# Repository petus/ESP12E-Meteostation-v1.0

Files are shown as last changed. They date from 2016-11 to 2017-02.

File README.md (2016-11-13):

# ESP12E-Meteostation-v1.0<br>
Meteostation with ESP12E (NodeMCU) and Si7021 (temperature and humidity sensor)<br>
<br>
PCB is designed in eagle<br>
The platic box is KM-27<br>
<br>
FLASHING: <br>
 1.) Choose NodeMCU v1.0 (ESP12E Module) in Tools -> Board<br>
for NodeMCU board:<br>
 2.) Upload the code<br>
for PCB with ESP12E:<br>
 2.) Press the Reset button and Flash button together and hold it<br>
 3.) Click to Upload the code in Arduino IDE<br>
 4.) In the moment when the console shows <strong>Uploading</strong> leave the Reset button, then the code will be uploaded<br>
<br>
websites: <br>
CZ http://chiptron.petus.cz/articles.php?article_id=93 <br>
EN http://time4ee.com/articles.php?article_id=33 <br>

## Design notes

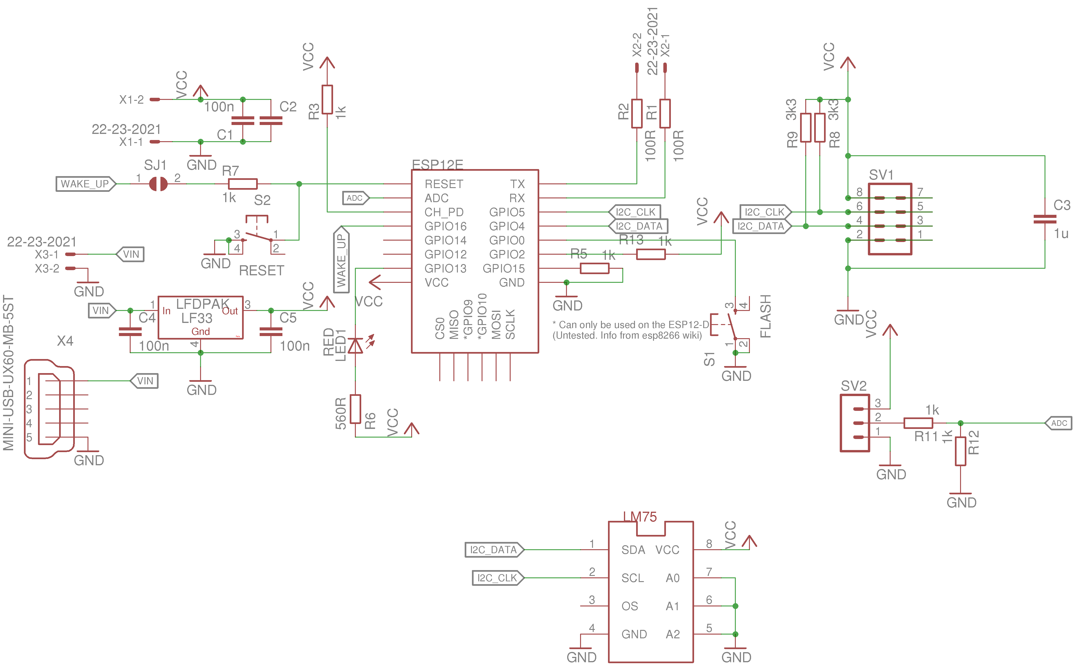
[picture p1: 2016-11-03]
ESP12E_ESP8266_Si7021_meteostation_SCH.png

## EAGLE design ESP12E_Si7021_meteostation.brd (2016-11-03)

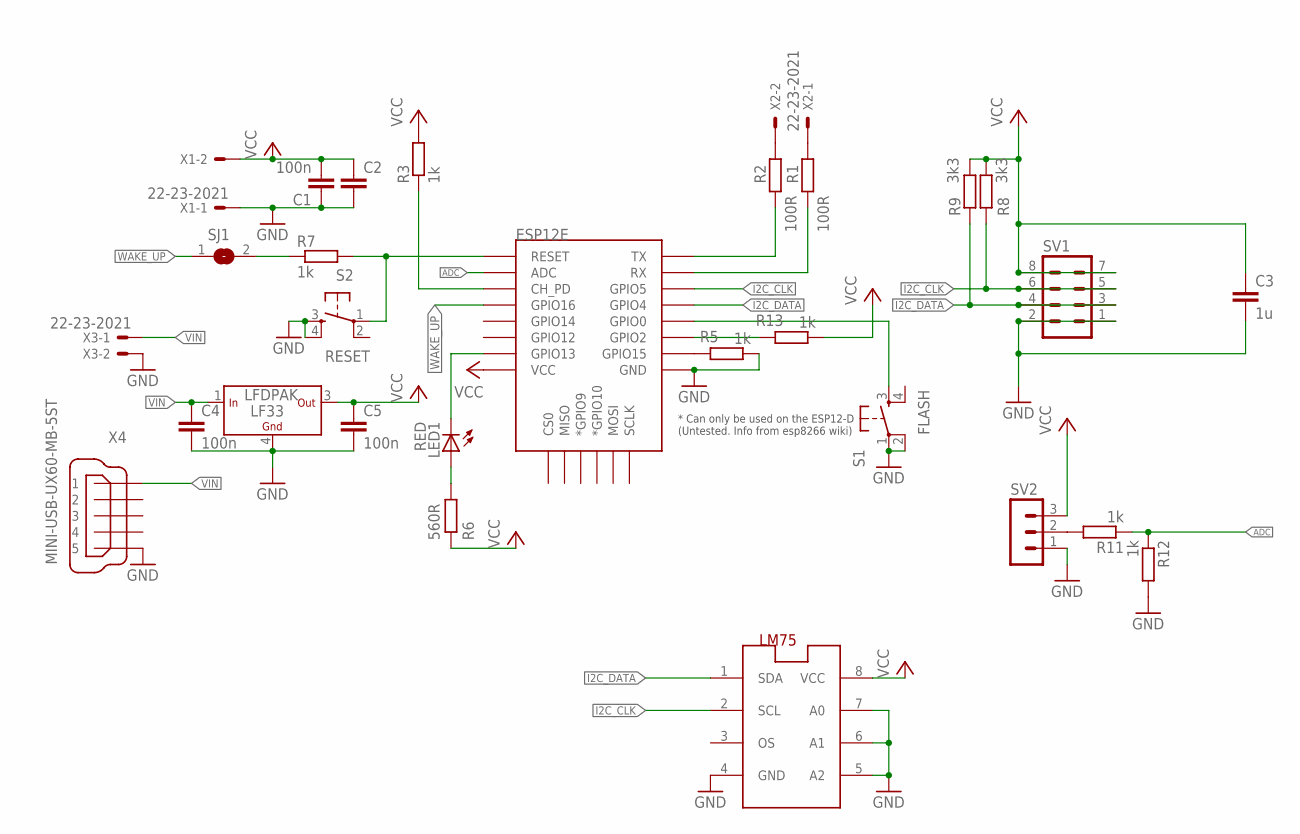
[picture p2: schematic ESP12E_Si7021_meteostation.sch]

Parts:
C1: 100n; C3225
C2: C-EUC1206; C1206
C3: 1u; C1206
C4, C5: 100n; C1206
ESP12E: ESP12ESMD; ESP12E-SMD
LED1: RED; CHIPLED_0603
LF33: LFDPAK; DPAK
LM75: LM75_ICN; SO8_LM75
R1, R2: 100R; R0805
R3: 1k; R1206
R5, R7, R13: 1k; R0805
R6: 560R; R0805
R8, R9: 3k3; R0805
R11, R12: 1k; M0805
S1: FLASH; TACTILE-PTH
S2: RESET; TACTILE-PTH
SJ1: SJ
SV1: MA04-2
SV2: MA03-1
X1, X2, X3: 22-23-2021
X4: MINI-USB-UX60-MB-5ST; UX60-MB-5ST

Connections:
ADC: ESP12E.ADC, R11.1, R12.1
GND: C1.1, C2.2, C3.2, C4.2, C5.2, ESP12E.GND, LF33.4 (GND), LM75.4 (GND), LM75.5 (A2), LM75.6 (A1), LM75.7 (A0), R5.1, R12.2, S1.1, S1.2, S2.3, S2.4, SV1.1, SV1.2, SV2.1, X1.1, X3.2, X4.5
I2C_CLK: ESP12E.GPIO5, LM75.2 (SCL), R8.1, SV1.5, SV1.6
I2C_DATA: ESP12E.GPIO4, LM75.1 (SDA), R9.1, SV1.3, SV1.4
unnamed: R1.2, X2.1
unnamed: R2.2, X2.2
unnamed: ESP12E.RXD0 (RX), R1.1
unnamed: ESP12E.TXD0 (TX), R2.1
unnamed: ESP12E.RESET, R7.2, S2.1
unnamed: ESP12E.GPIO15, R5.2
unnamed: ESP12E.CH_PD, R3.1
unnamed: LED1.A, R6.2
unnamed: ESP12E.GPIO13, LED1.C
unnamed: R7.1, SJ1.2
unnamed: ESP12E.GPIO2, R13.2
unnamed: ESP12E.GPIO0, S1.3
unnamed: R11.2, SV2.2
VCC: C1.2, C2.1, C3.1, C5.1, ESP12E.VCC, LF33.3 (OUT), LM75.8 (VCC), R3.2, R6.1, R8.2, R9.2, R13.1, SV1.7, SV1.8, SV2.3, X1.2
VIN: C4.1, LF33.1 (IN), X3.1, X4.1
WAKE_UP: ESP12E.GPIO16, SJ1.1

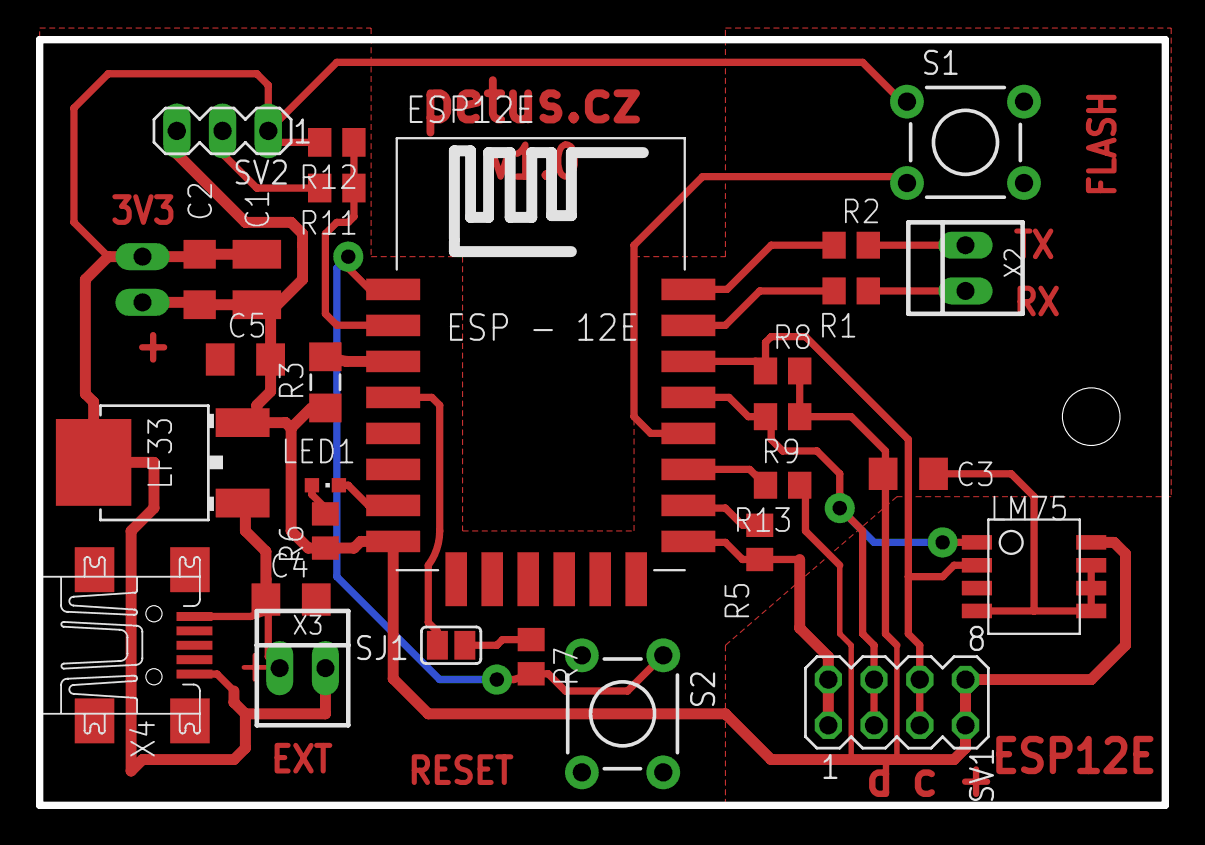
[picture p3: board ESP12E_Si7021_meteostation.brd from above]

Board: 2 copper layers, 62.5 x 42.5 mm, 29 parts (1 on the bottom side), 20 nets.

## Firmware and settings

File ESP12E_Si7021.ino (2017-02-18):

/**
 * NodeMCU (ESP12E) + Si7021 = Meteostation
 *
 * made by Petus
 * http://petus.cz
 * http://chiptron.cz
 * http://time4ee.com
 *
 * Si7021 library - https://github.com/LowPowerLab/SI7021
 * 
 * It's working!!!
 */

#include <ESP8266WiFi.h>
#include <Wire.h>
#include <SI7021.h>

#define SDA 4 // GPIO4 on D2
#define SCL 5 // GPIO5 on D1

#define ARDUINO_ARCH_ESP8266

#define SLEEP_DELAY_IN_SECONDS  30

const char* ssid     = "SSID";
const char* password = "PASSWORD";

const char* host = "HostName.tmep.cz";

SI7021 sensor;

void setup() {
  unsigned int numberOfConnections= 0;
  
  Serial.begin(9600); // Open serial connection to report values to host
  delay(10);
   
  Serial.println();
  Serial.println();

  Serial.print("Meteostation by Petus\n");
  Serial.print("http://chiptron.cz\n");
  Serial.print("http://time4ee.com\n");
  Serial.println("FW version: 1.2\n");
  
  Serial.print("Connecting to ");
  Serial.println(ssid);
  
  WiFi.begin(ssid, password);
  
  while (WiFi.status() != WL_CONNECTED) {
    delay(500);
    Serial.print(".");
    numberOfConnections++;

    Serial.println("Number Of Connections:");
    Serial.println(numberOfConnections);

    // if ESP12E can't connect to WiFi -> enable deep.sleep
    if (numberOfConnections > 10)
    {
        //if you want to use deep sleep, connect RST with D0 (GPIO16)
        //ESP.deepSleep(SLEEP_DELAY_IN_SECONDS * 1000000, WAKE_RF_DEFAULT);
        delay(1000);
        return;
    }
  }

  Serial.println("");
  Serial.println("WiFi connected");  
  Serial.println("IP address: ");
  Serial.println(WiFi.localIP());
  sensor.begin(SDA,SCL);

}


void loop() {
  int temperature = sensor.getCelsiusHundredths();
  unsigned int humidity = sensor.getHumidityPercent();

  Serial.print("connecting to ");
  Serial.println(host);
  // Use WiFiClient class to create TCP connections
  WiFiClient client;
  const int httpPort = 80;
  if (!client.connect(host, httpPort)) 
  {
    Serial.println("connection failed");
    return;
  }

    // We now create a URI for the request
  String url = "/index.php?";

  Serial.print("Requesting URL: ");
  Serial.println(url);

  //temperatureH = String(temperature/100.0, 2);

  // This will send the request to the server
    client.print(String("GET ") + url + "tempC=" + String(temperature/100.0, 2) + "&humV=" + humidity + " HTTP/1.1\r\n" +
             "Host: " + host + "\r\n" + 
             "Connection: close\r\n\r\n");

  delay(10);

  // Read all the lines of the reply from server and print them to Serial
  Serial.println("Respond:");
  while(client.available())
  {
    String line = client.readStringUntil('\r');
    Serial.print(line);
  }

  Serial.println();
  Serial.println("closing connection");

  //if you want to use deep sleep, connect RST with D0 (GPIO16)
  //ESP.deepSleep(SLEEP_DELAY_IN_SECONDS * 1000000, WAKE_RF_DEFAULT);
  delay(10000);
  
}

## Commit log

2016-10-30 Add files via upload
    schematic
2016-10-30 Add files via upload
    schematic and PCB
    [ESP12_SHT2x_meteostation.brd, ESP12_SHT2x_meteostation.sch]
2016-11-13 Update ESP12E_Si7021.ino
    bug of minus values
    [ESP12E_Si7021.ino]
2017-02-18 Update ESP12E_Si7021.ino
    removed the calculation of temperature
    used String instead of calculation
    thanks Arcao (https://plus.google.com/+MartinSloup)

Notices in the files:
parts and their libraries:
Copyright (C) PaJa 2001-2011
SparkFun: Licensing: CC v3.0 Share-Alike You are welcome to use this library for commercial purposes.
